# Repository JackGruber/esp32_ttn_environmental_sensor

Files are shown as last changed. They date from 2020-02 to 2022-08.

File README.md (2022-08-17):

# ESP32 battery/solar powerd environmental sensor

Battery/solar-powered ESP32 TTN (LoraWAN) sensor node for measuring temperature, humidity, air pressure, fine dust, UV and LUX.

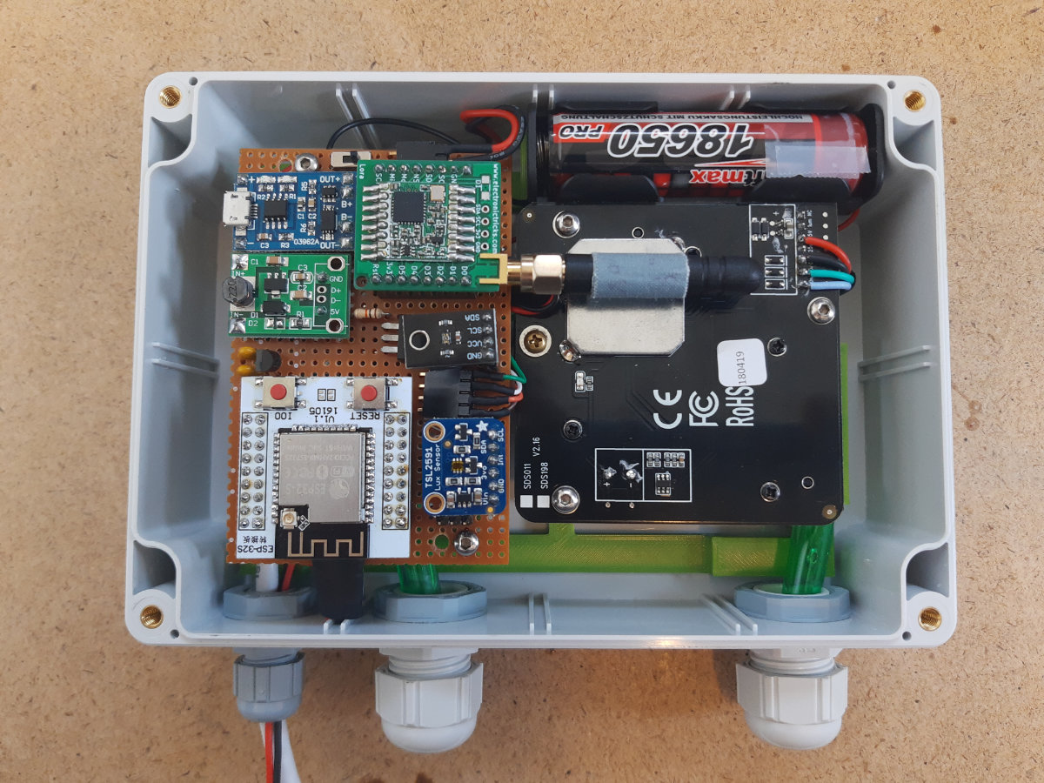
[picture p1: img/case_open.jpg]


The microcontroller is an ESP32, but I don't use a ready-made module, because they need too much power even in DeepSleep. Instead I use a WROOM32 module.

The following sensors are used: SDS011 (Fine dust),  BME280 (Temperature / Humidity / Air pressure), VEML6075 (UV Index) and TSL2591 (LUX).

For power supply a 18650 battery is used, which is charged via solar pannel and TP4056. Since the ESP32 and the sensors require 3.3 V, the MCP1700-3302E voltage regulator is used, because the a full loaded 18650 provieds 4.2V and the ESP32 is only rated for 3.0 V~3.6 V. Only the SD011 needs 5V, these are generated with a step-up converter.

Since the SDS011 also needs too much current during the DeepSleep phases of the ESP32, it is switched on and off by N-channel MOSFET (IRL3103PBF).

Every 5 minutes the measurements are sent via LoRaWAN. I retrieve the values via MQTT and Telegraf and visualize them in a Grafana dashboard.

The whole thing was then installed in a weatherproof housing, the cables and the AAA are led down by Cable Glands to the outside to keep the housing as waterproof as possible. Only the BME280 was mounted outside in a Stevenson Screen.

## Components / BOM

* 1x WROOM32 module
* 1x TP4056 module
* 1x MCP1700-3302E
* 1x Solar panel 6V 3W (180x150 mm)
* 1x 18650 battery
* 1x 18650 battery holder
* 1x 5V DC-DC boost converter module
* 1x RFM95 module
* 1x RFM95 breadboard
* 1x BME280 sensor
* 1x SDS011 module
* 1x TSL2591 sensor
* 1x IRL3103PBF
* 1x VEML6075 sensor
* 1x Housing IP65 171 x 121 x 55 mm
* 1x Cable Gland PG7
* 2x Cable Gland PG11
* 7x Standoff/Spacer 20 mm
* Aquarium hose
* ...

## Schematic

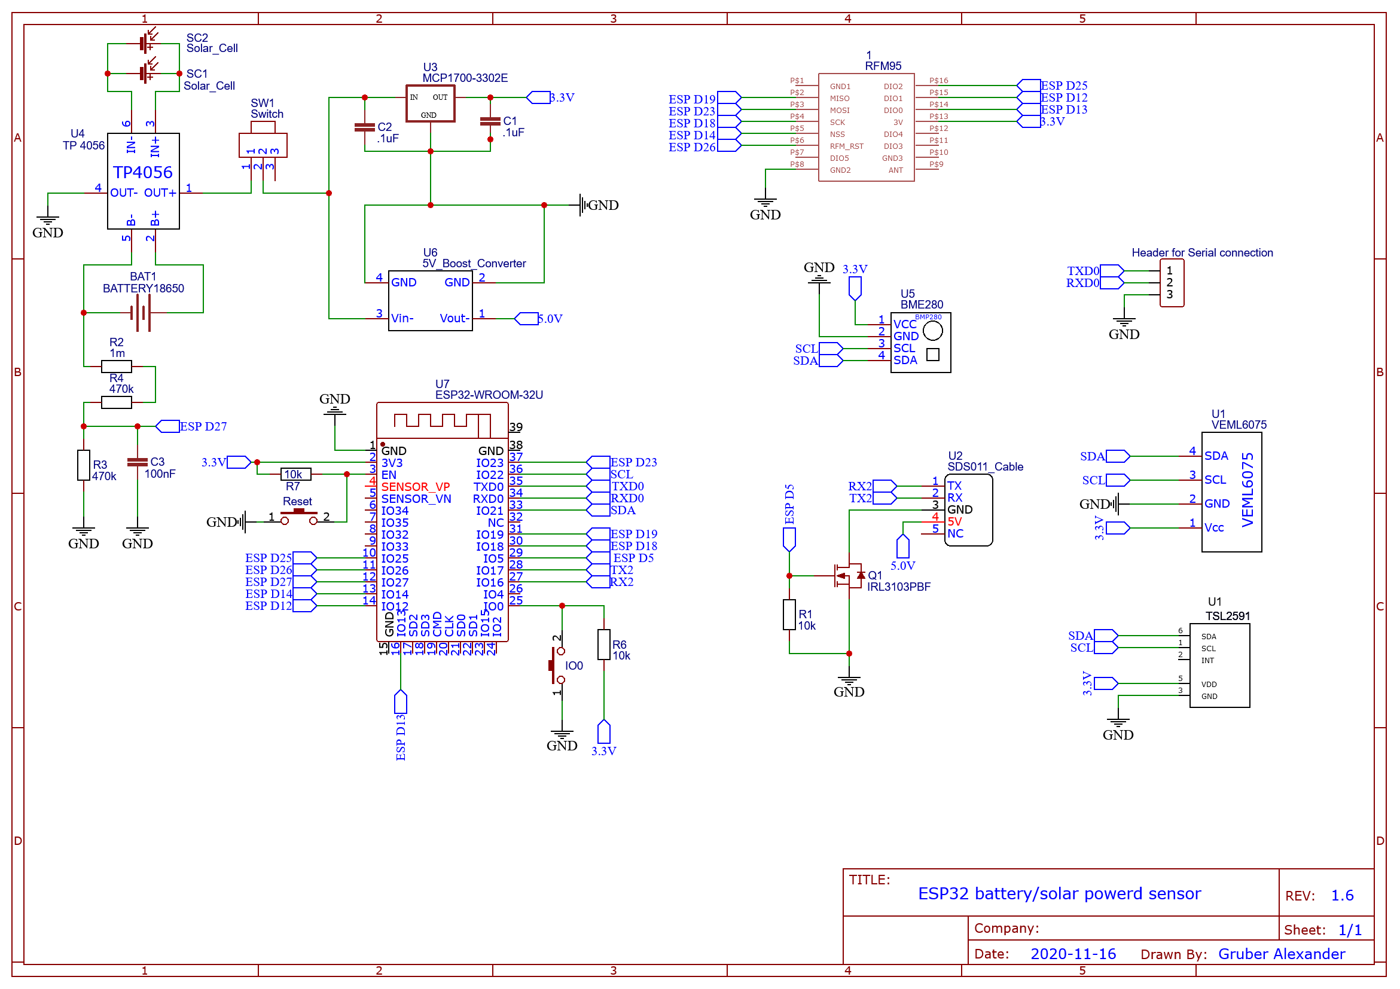
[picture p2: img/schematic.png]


### TP4056 modification

The charging LED lights up as soon as the solarpannel supplies some current. However, this will cause the LED to discharge the battery when there is little sunshine.

To prevent this, I have soldered out the charging LED.

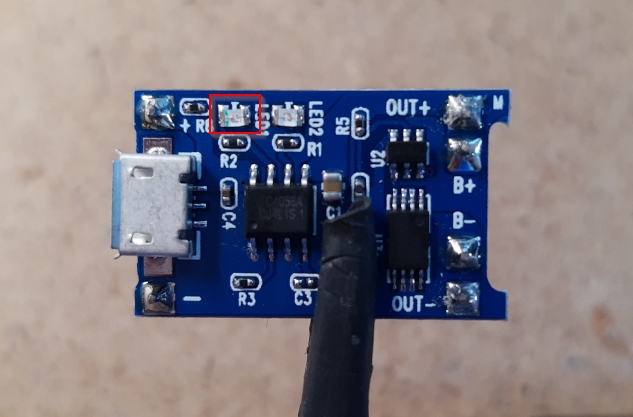
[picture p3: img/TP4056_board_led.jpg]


### Solar panel

The simple solar panels with plastic covers do not withstand UV radiation and wether conditions very well outdoors and the performance decreases drastically.

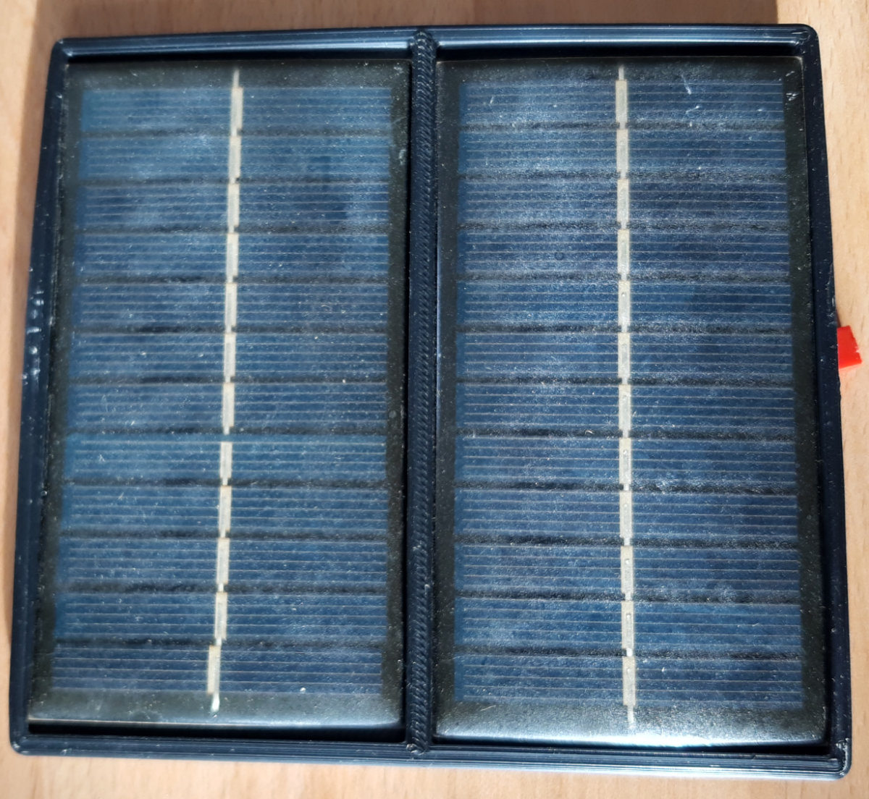
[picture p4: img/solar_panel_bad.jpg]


Therefore, I now use a slightly better one with a glass cover.

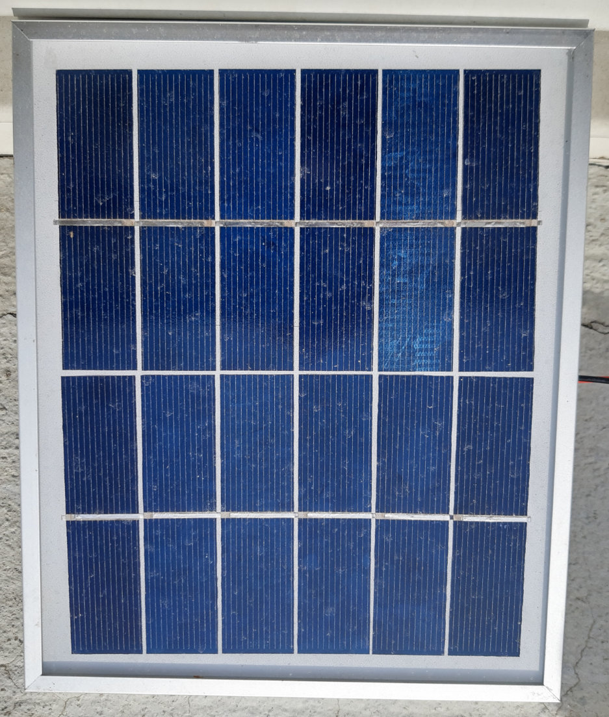
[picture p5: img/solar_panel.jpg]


### RFM95 Breadboard

I have use the [iBrick / RFM95LORA Breadboard](https://github.com/iBrick/RFM95LORA_Breadboard) to make the RFM95 module breadboard/hole matrix board friendly. You can direct download the [Gerberfile](https://github.com/iBrick/RFM95LORA_Breadboard/blob/master/RFM95Breadboard.rar) from the Git repro.

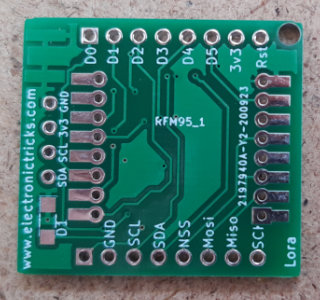
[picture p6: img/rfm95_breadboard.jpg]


## Power consumption

| Mode | Power consumption |
| ---- | --- |
| SDS011 measurement (30 sec) | 175 mA |
| LoRa activity | 7 mA |
| DeepSleep | 52 uA |

### Battery levels overview (Measuring and data send interval every 5 minutes)

The data are still from the use with the 2W solar pannel!

#### No charge current  

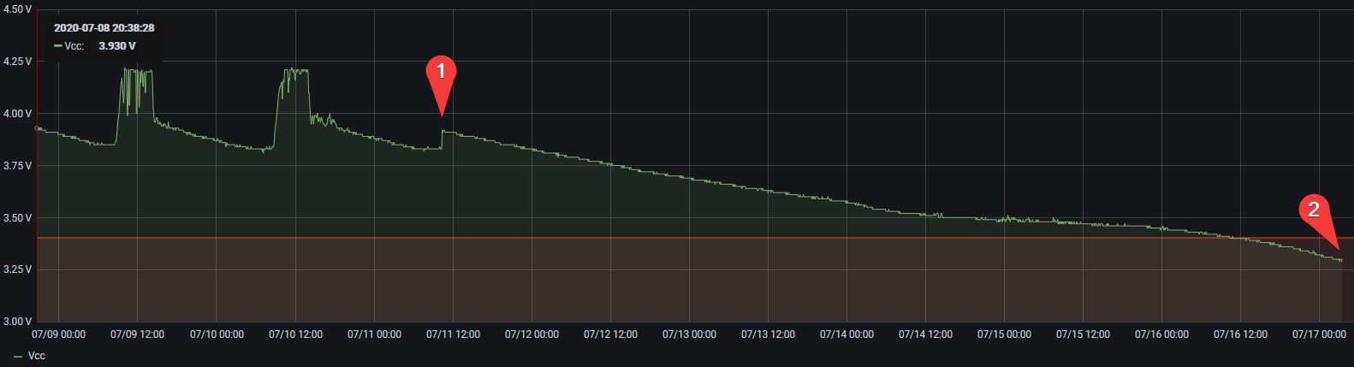
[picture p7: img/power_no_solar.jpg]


`1` = Disconnect solar pannel, `2` = Last data packet sent

#### Normal operation

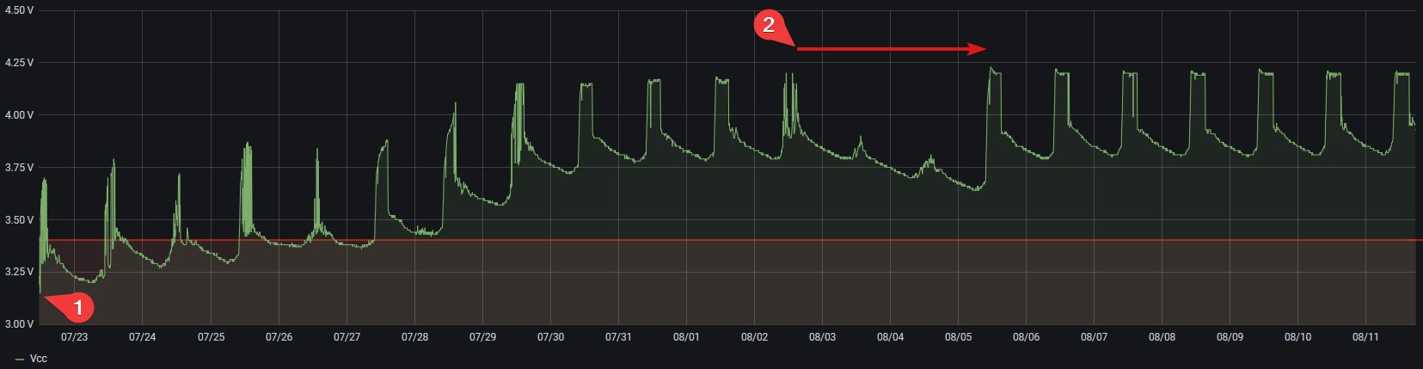
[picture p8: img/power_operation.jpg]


`1` = First data packet sent after after approx. 6 houre of charge, `2` = Rainy days

## TTN payload decoder

```javascript
function decodeUplink(input) {
  var decoded = {};
  
  decoded.vcc = (input.bytes[0] + 200)/100;

  if(input.bytes[1] != 255 || input.bytes[2] != 255)
  {
    decoded.pm25 = ((input.bytes[1] << (8*1) | input.bytes[2] << (8*0)) / 10);
  }

  if(input.bytes[3] != 255 || input.bytes[4] != 255)
  {
    decoded.pm10 = ((input.bytes[3] << (8*1) | input.bytes[4] << (8*0)) / 10);
  }
  
  if(input.bytes[5] != 255 || input.bytes[6] != 255)
  {
    decoded.temperature = ((input.bytes[5]<<24>>16 | input.bytes[6]) / 10);
  }
  
  if(input.bytes[7] != 255)
  {
    decoded.humidity = input.bytes[7];
    decoded.humidity &= ~(1 << 7);
    if(input.bytes[7] >> 7 == 1) { decoded.humidity +=0.5 }
  }
  
  pressure = (input.bytes[8] << (8*0) | input.bytes[9] << (8*1) | input.bytes[10]  << (8*2)) / 100;
  if(pressure >= 300 && pressure <= 1100) { decoded.pressure = pressure }

  if(input.bytes[11] != 255) decoded.uvi = input.bytes[11] / 10;

  if(input.bytes[14] != 255)
  {
    decoded.lux = (input.bytes[12] << (8*0) | input.bytes[13] << (8*1) | input.bytes[14]  << (8*2)) / 100;
  }
  
  return {
    data: decoded,
    warnings: [],
    errors: []
  };
}
```

## 3D Printing

### PCB and SDS011 mounting

The STL and Fusion 360 Archive files are included in the 3D folder

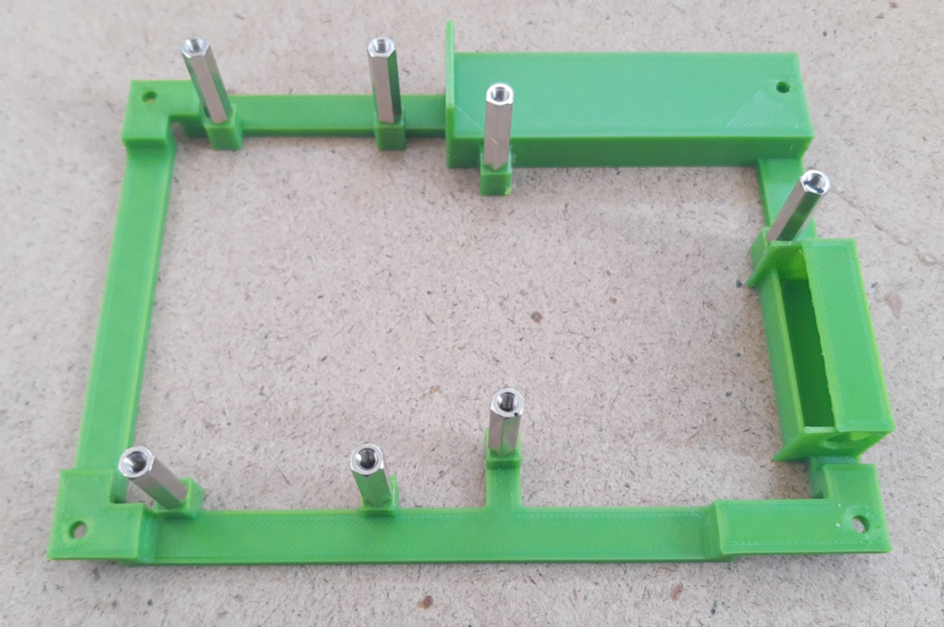
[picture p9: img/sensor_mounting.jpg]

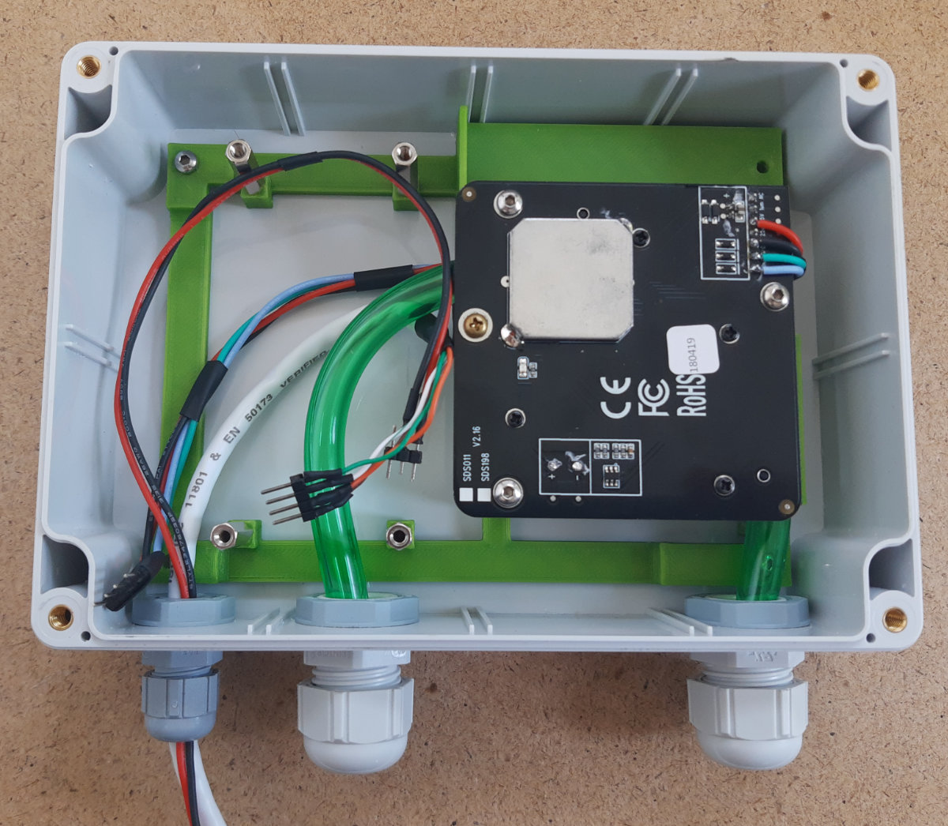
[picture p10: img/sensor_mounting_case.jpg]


### Stevenson Screen

For the Stevenson Screen, I have used a modle from [Thingiverse](https://www.thingiverse.com/thing:3044446/files)

## Pictures

Grafana Dashboard for the visualization of the measured values.

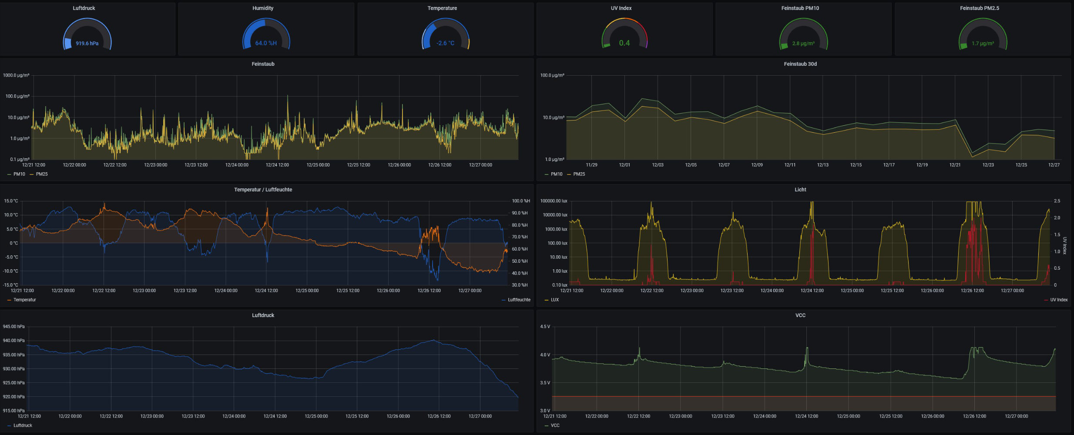
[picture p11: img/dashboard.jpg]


The whole mounted outside on the windowsill.

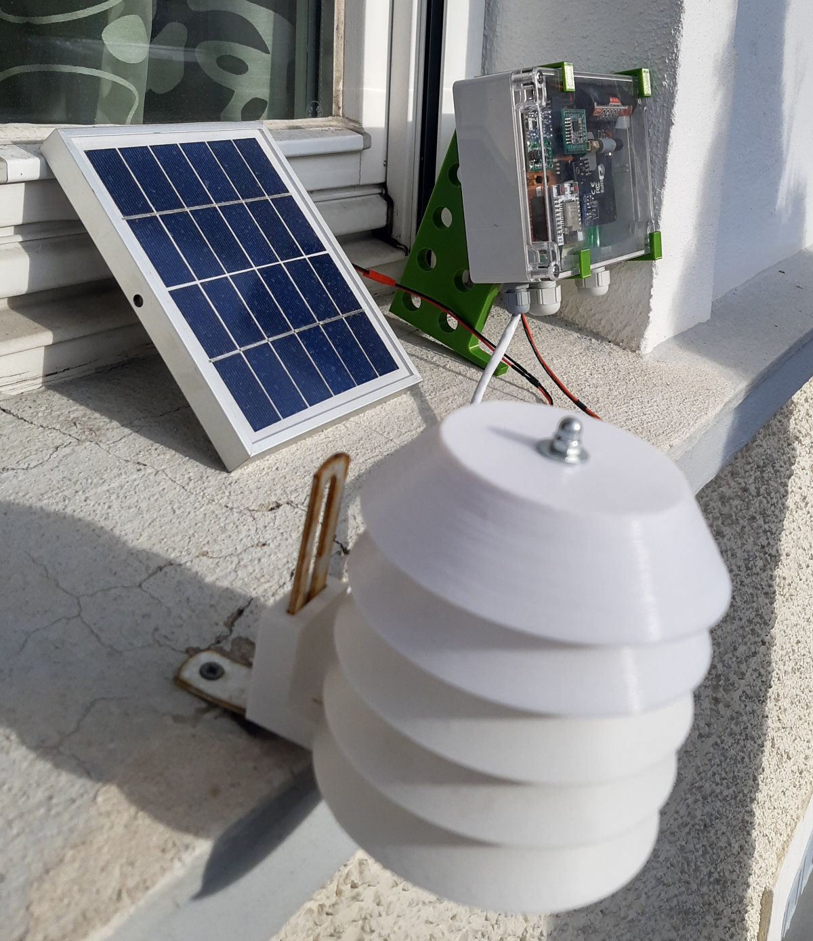
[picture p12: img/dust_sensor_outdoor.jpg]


## Links

* [Thingiverse Stevenson Screen](https://www.thingiverse.com/thing:3044446/files)
* [iBrick / RFM95LORA Breadboard](https://github.com/iBrick/RFM95LORA_Breadboard)

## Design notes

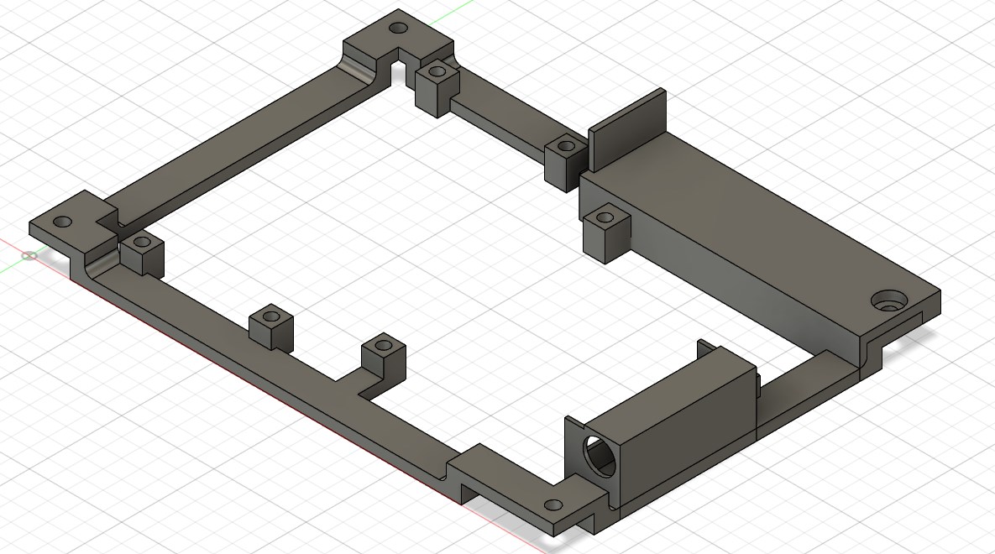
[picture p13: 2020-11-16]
img/sensor_mounting_3d.jpg

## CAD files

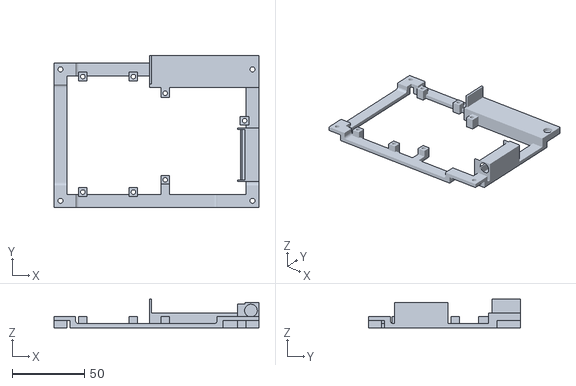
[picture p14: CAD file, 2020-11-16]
3D/sensor_mounting.stl
142.0 x 105.0 x 20.0

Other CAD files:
3D/sensor_mounting.f3d

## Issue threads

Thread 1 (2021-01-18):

Not sending data or saving session

kevin192291, 2021-01-18:
Hello,
I am attempting to run this on a Heltec v2 lora board.
The issue is that it connects, then fails to send any data, sleeps, and re-connects. Running the LoraWANDebug(RTC_LMIC);
displays this:
```
LMIC.opmode:
LMIC.seqnoUp = 0
LMIC.globalDutyRate = 0 osTicks, 0 sec
LMIC.globalDutyAvail = 0 osTicks, 0 sec
LMICbandplan_nextTx = 525736 osTicks, 8 sec
os_getTime = 527196 osTicks, 8 sec
LMIC.txend = 525736
LMIC.txChnl = 5
Band 	avail 		avail_sec	lastchnl 	txcap
0	0		0		0		0
1	0		0		5		100
2	0		0		0		0
3	0		0		0		0
```
and seqnoup is always 0, dispite successfully authing with TTN.
It may be worth mentioning that I am on the AS923 JP freq.

Any idea why it will not send? Could it be the AS freq that it isn't liking?
I don't have a US Gateway so I can't test with 915mhz.

Thanks for the help! I would really love to use this code!!!!

I should add that with the same settings, the https://github.com/mcci-catena/arduino-lmic does send data without a problem.

JackGruber, 2021-01-18:
Could you post a complet output from the console.
On 915 Mhz is my workaround for the DutyCycle not working. Possible this is also on AS923.

kevin192291, 2021-01-18:
Thanks for that really fast reply!
Here is a fully cycle of the output:
```
ets Jun  8 2016 00:22:57

rst:0x5 (DEEPSLEEP_RESET),boot:0x13 (SPI_FAST_FLASH_BOOT)
configsip: 0, SPIWP:0xee
clk_drv:0x00,q_drv:0x00,d_drv:0x00,cs0_drv:0x00,hd_drv:0x00,wp_drv:0x00
mode:DIO, clock div:1
load:0x3fff0018,len:4
load:0x3fff001c,len:1216
ho 0 tail 12 room 4
load:0x40078000,len:9720
ho 0 tail 12 room 4
load:0x40080400,len:6352
entry 0x400806b8
LMIC Version: 3.3.0.0
LoRaWAN_Setup ...
Saved seqnoUp: 0
Packet queued
9562: EV_JOINING
214923: EV_TXSTART
Runtime: 5 seconds
579784: EV_JOINED
netid: 0
devaddr: A7E3C2
artKey: 32A0365EA4E8F33C617B24F75637B65
nwkKey: F0D9E09E117757E53E1011AFDF735F64
579808: EV_TXCOMPLETE
Go to DeepSleep ...
Runtime was: 9 seconds
Save LMIC to RTC ...

```
I am not sure if that helps at all. That is what I am seeing in my serial out.

JackGruber, 2021-01-18:
Hm ...
Join is ok and a msg was send. Then a seqnoUp of 1 shouldbe saved ...
But in the output the seqnoUp is 0 and the EV_TXCOMPLETE event says data was send.
Could you try the code from https://github.com/JackGruber/ESP32-LMIC-DeepSleep-example only for testing the DeepSleep

kevin192291, 2021-01-18:
Yes! Actually I have,
I got the same exact result!
Here is what I am seeing on TTN side:
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
but never any data

JackGruber, 2021-01-18:
> Code that accesses the content of the LMIC structure may need to be modified, as some of the fields have been renamed, or rearranged.
From the LMIC changelog ...

I think the codeneed a rework to run with lmic > 3.0.99
You can try it with the version 3.0.99

kevin192291, 2021-01-19:
Just to be clear, It is the https://github.com/mcci-catena/arduino-lmic version of the library right?
I get MAX_BANDS being missing on version 3.0.99 (if installed from the library manager) and all versions of 3.0.99.x if
I download the zips from github, also, Anything before 3.0.0 and I get missing case items such as `case EV_RXSTART` and `case EV_JOIN_TXCOMPLETE`
If there is anything I can do to assist getting this working, I would absolutely love to help. This seems really really important for LoRa nodes!!!

JackGruber, 2021-01-19:
OK, I have checkt my projects.
I use the LMIC version 3.1.0, 3.2.0, but it works also fine with 3.3.0.

>Just to be clear, It is the https://github.com/mcci-catena/arduino-lmic version of the library right?

Yes, I saw you have opened an issue there too.

kevin192291, 2021-01-19:
Sounds good. I Think the issue I opened on the Arduino-lmic page may be a bit different.
I figure I will try to handle the re-join and the data sending separately. Thanks, I will keep trying on these. I appreciate the support!

Closed 2021-01-20.

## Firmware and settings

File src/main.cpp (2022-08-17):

#include <Arduino.h>
#include <particle.h>
#include <lorawan.h>
#include <functions.h>
#include <global.h>
#include "soc/soc.h"
#include "soc/rtc_cntl_reg.h"
#include "version.h"
#include "version_build.h"
#include "bme280.h"
#include "esp32-hal-cpu.h"
#include <veml6075.h>
#include <power.h>
#include "settings.h"
#include <tsl2591.h>

void setup()
{
    WRITE_PERI_REG(RTC_CNTL_BROWN_OUT_REG, 0); // Disable Brownout Detector
    setCpuFrequencyMhz(10);
    Serial.begin(115200);
    Serial.println(F("Starting environment sensor ..."));
    Serial.println("Sketch: " VERSION_MAJOR "." VERSION_MINOR "." VERSION_PATCH "." BUILD_COMMIT "-" BUILD_BRANCH);
    Serial.println("Builddate: " BUILD_DATE " " BUILD_TIME);
    LoraWANPrintVersion();
    PrintResetReason();

    Serial.print("CPU Speed: ");
    Serial.print(getCpuFrequencyMhz());
    Serial.println(" MHz");

    SetupPins();

    Wire.begin();
    I2CScanner();

    if (ReadVBat() < 3300)
    {
        Serial.println("Goto DeepSleep (VBat to low)");
        PowerDeepSleepTimer(LORA_TX_INTERVAL);
    }

    // Setup BME280 and print values
    if (I2CCheckAddress(0x76))
    {
        BME280Setup();
        BME280PrintValues();
    }
    else
    {
        Serial.println("No BME280 found!");
    }

    // Setup VEML6075
    if (I2CCheckAddress(0x10))
    {
        VEML6075Setup();
        VEML6075GetUVI();
    }
    else
    {
        Serial.println("No VEML6075 found!");
    }

    // Setup TSL2591
    if (I2CCheckAddress(0x29))
    {
        TSL2591Setup();
        TSL2591GetLux(true, true);
    }
    else
    {
        Serial.println("No TSL2591 found!");
    }

    // Setup SD011 and read values
    ParticlePower(true);
    ParticleSetup();
    ParticleRead(true, true, PM25, PM10);
    ParticlePower(false);

    LoRaWANSetup();
}

void loop()
{
    LoraWANDo();
}

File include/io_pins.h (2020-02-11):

// PIN definition for module
#define PIN_LMIC_NSS  14
#define PIN_LMIC_RST  26
#define PIN_LMIC_DIO0 13
#define PIN_LMIC_DIO1 12
#define PIN_LMIC_DIO2 25

#define PIN_ENABLE_SD011 5
#define PIN_VBAT 27

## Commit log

2020-02-08 Change to ESP32
2020-02-08 Power on/off SDS011
2020-02-08 change for ESp32
2020-02-08 Add SetupPins and PrintResetReason
2020-02-08 Time for power up
2020-02-08 Chnage wait time after power / init
2020-02-08 Send ESP32 to light sleep (no reset)
    [particle.cpp]
2020-02-11 Change Pin for default SDA/SCL Pin
2020-03-26 Bug: correct analog read max value
    [functions.cpp]
2020-04-04 Print reset reasons
2020-04-04 Add serial print for Vcc read
2020-04-04 calibrate readings
2020-04-04 Update schematic
2020-04-13 Add additional vars for Saving/Loading and correct memcpy Bug (src / dest swapt and copy size)
    [lorawan.cpp]
2020-08-18 Battery levels overview
2020-08-22 Add BME280 sensor
2020-08-22 enlarge array for BME280 sensor
2020-08-30 reduce CPU speed to save power
2020-08-30 Change to println
2020-08-30 Power off ADC in DeepSleep
2020-08-30 VBat calibrated
2020-08-30 Add Power consumption table
2020-09-17 Print LMIC Version
2020-09-17 Reset LMIC Bandplan because we cant keep track of millis during deepsleep. Otherwise we run into dutycycle problems
    [lorawan.cpp]
2020-09-17 Add temperature, humidity and pressure only on valide values
2020-09-19 Add def PRINTDEBUGS
2020-09-19 Print runtime every 5 sec
2020-09-20 Add VEML6075 Sensor
2020-09-20 Print runtime info every 5 sec
2020-09-20 Add I2C sensor check
2020-09-20 Add I2CScanner
2020-10-02 Add DeepSleep on low power
2020-10-03 Shutdown sensor after configuration
2020-10-03 Add TSL2591 sensor
2020-10-03 Add TSL2591 sensor to schematic
2020-11-16 Add case image
2020-11-16 Change Housing
2020-11-16 Add switch
2020-11-16 Add Sensor mounting
    [sensor_mounting.f3d, sensor_mounting.stl]
